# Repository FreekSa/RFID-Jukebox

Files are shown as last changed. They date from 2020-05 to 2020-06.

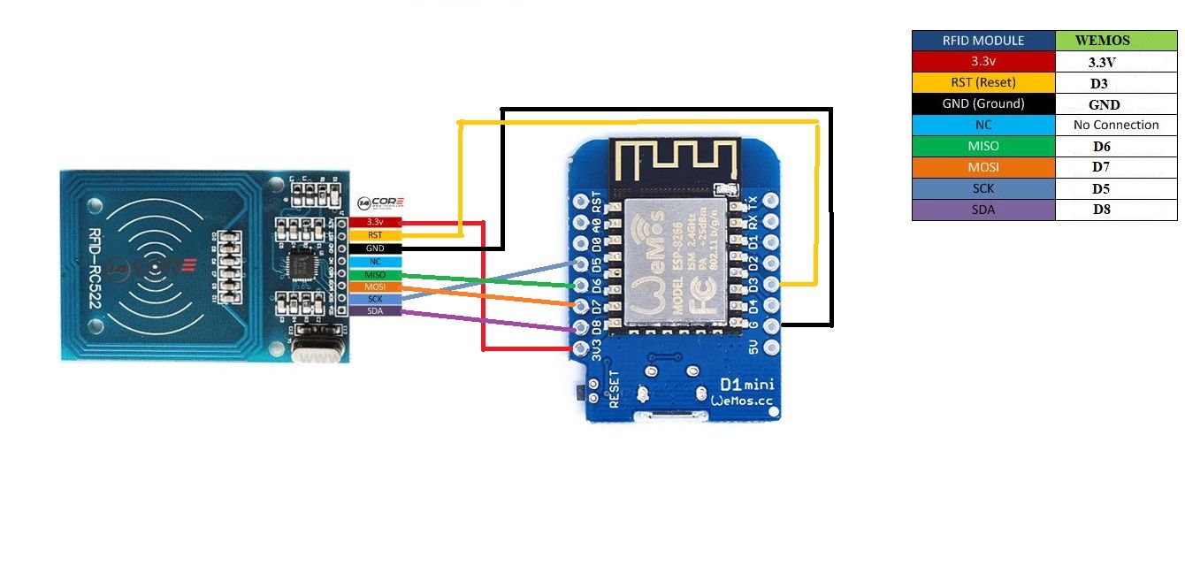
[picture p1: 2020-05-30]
rfid pinout.jpg

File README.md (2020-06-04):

# RFID-Jukebox

Ik zag een artikel passeren over iemand die een kickstarter project had nagebouwd.
Link: https://imgur.com/a/aiS5xp7
Ik had nog een Wemos D1 mini v3 liggen die nog geen bestemming had gekregen en een raspberry pi 3. Daarnaast had ik reeds een RFID module (MFRC522) met enkele NFC tags.

Na wat zoeken vond ik zijn code op github: https://github.com/paulmassen/volumio-rfid-esp8266
Zijn code was onvolledig; na een test bleek al snel dat hij een kaart scant en een link stuurt naar Volumio, maar als een tag bleef liggen speelde hij na 3 seconden het nummer opnieuw af. Met een "if" structuur is deze aangepast. Functie: Nu leest hij de tag en als deze tag voordien al gescand is dan moet hij niks doen.

Wat heb je nodig voor dit project (bijhorende links waar ik mijn materiaal kocht):

Wemos D1 mini v3: https://opencircuit.be/Product/WeMos-D1-mini-V3.1-Wifi-Module</br>
NFC reader (headers moeten zelf gesoldeerd worden): https://opencircuit.be/Product/RC522-RFID-Reader-writer-module-kit-13.56MHz</br>
Raspberry pi 3 (elke pi met ingebouwde wifi zou moeten werken): https://www.kiwi-electronics.nl/raspberry-pi-3-model-b-plus</br>
HDMI naar VGA adapter: kost 5€ in de action. We gebruiken deze om de audio jack die achteraan de vga poort zit te gebruiken en zo mooie kwaliteit als output te krijgen.</br>
NFC tags/stickers: kocht op alliexpress voor 1€ 10 NFC stickers (In België betaal je snel 15€ voor 10 stickers) Ik kocht er 50 in een keer en betaalde 5€ excl verzendkosten. (moet je wel een maand wachten).

Daarnaast heb ik zelf een 3D printer en designde dus de case, deksel met holte voor de schijfjes en aparte schijfjes in fusion360 (gratis software voor hobbyisten ;-) . (stl's zijn toegevoegd, alsook fusion files)

Aan jou om alles te printen. Kan bvb met online service 3DHubs of in een fablab/makerspace in je buurt.
Nu we alles hebben kunnen we alles in elkaar prutsen. In bijgevoegde foto zie je hoe je de nfc reader verbind met je wemos D1. (pinnen heb ik niet aan de RFID gesoldeerd, wel aan de wemos D1. (eigen keuze :) ).

Nu alles verbonden is, volgt het programmeren van de wemos D1.
Open het "DumpInfo.ino" bestand in de ARDUINO IDE.
Arduino kent ons boardje niet. Dus moeten we een link toevoegen zodat hij deze kent. Dit doe je als volgt:
Klik op Bestand, Voorkeuren en plak de link: Additionele boards beheer URL: http://arduino.esp8266.com/stable/package_esp8266com_index.json

Nu kent hij ons borde, maar om de NFC lezer te gebruiken moeten we een bibliotheek installeren. Klik daarvoor op: Hulpmiddelen, Bibliotheken beheren. Zoek naar: MFRC522 en klik op Installeer.

Daarna selecteer je bij Boards: Wemos D1 mini pro V3. en bij poorten de juist COM.

Als alles is aangesloten open je het bestand: "DumpInfo.ino", dit vind je in de github of onder: Voorbeelden, MFRC522, Dumpinfo.
Verander SSPin naar D8 ipv 10 en upload naar je bord. Ga naar Hulpmiddelen en open de seriele poort. Controleer dat hij zeker op 9600 Baud staat. Scan je tag en kopieer ergens de Tag UID (vb Kladblok). Scan al je tags die je wil gebruiken en maak een overzichtje naar welke afspeellijst je deze wil koppelen.

Nu open je de "RFID_met_volumio.ino". Je plakt je tag onder clients tag. (verander deze met jou gescande UID per tag).
Daaronder verander je de url naar jou afspeellijst (leg ik uit onder het onderdeel Volumio)
Daarna uploaden naar je board (vergeet je poort niet te selecteren!)

Volumio

Extra info: Als Volumio met geen wifi-netwerk verbonden is dan maakt hij een eigen hotspot aan. Deze heet Volumio en gebruiken we.
Wachtwoord verander je in de volumio settings. Deze vind je door met de hotspot te verbinden en in je browser naar: volumio.local te surfen.

Volumio flashen op je sd kaart doe je bvb via win32DiskImager. Dit leg ik niet verder uit. Hiervan vind je veel tutorials op internet. zoek onder: img naar sd kaart flashen.

Verbindt via wifi op je pc met Volumio. Wachtwoord: Volumio. Surf naar http://volumio.local

Als je volumio voor de eerste keer start stelt hij wat vragen. Belangrijk is dat je HDMI als default selecteert en niet de audio jack. De raspberry pi's audio jack heeft geen versterker dus produceert ruis. Via HDMI kan je dan achteraan de adapter je jack insteken.

Nu alles van geluid in orde is moeten we afspeellijsten maken. Kort uitgelegd: De wemos stuurt een link naar een afspeellijst die in volumio staat. Je gaat dus naar muziekbibliotheek en steekt een usb stick in met muziek of muziek die op de sd kaart staat (leg ik zo meteen uit hoe je er op zet). Klik op de 3 puntjes naast een mapje en klik op toevoegen aan afspeellijst. Geef een naam en klik op Nieuw.

Muziek overzetten vanop je pc:
Open een verkenner en typ in de url: \\volumio.local
Nu kan je muziek in de Internal storage slepen en vind je terug in volumio in Muziekbibliotheek.

ARDUINO:
Vul de naam van je afspeellijst in de plaats van mijn afspeellijstnamen in arduino met enkele regels daarboven je gescande tagnummer per afspeellijst. Vergeet niet: een spatie tussen je afspeellijst doe je weg en vul je %20 in. (zie in mijn namen van afspeellijsten in het bestand).

Nu hoef je zelf nog je foto's te maken. (mijn breedte van fotos was 2.7cm om zo te passen. Veel prutswerk om deze mooi op het schijfje te krijgen. Op de achterkant plak je dan je nfc sticker. Mooiste kwaliteit is printen op fotopapier (mat zodat de vingerafdrukken er niet aanplakken).

Vergeet geen play en pauze schijfje! :-)

Succes en veel plezier!

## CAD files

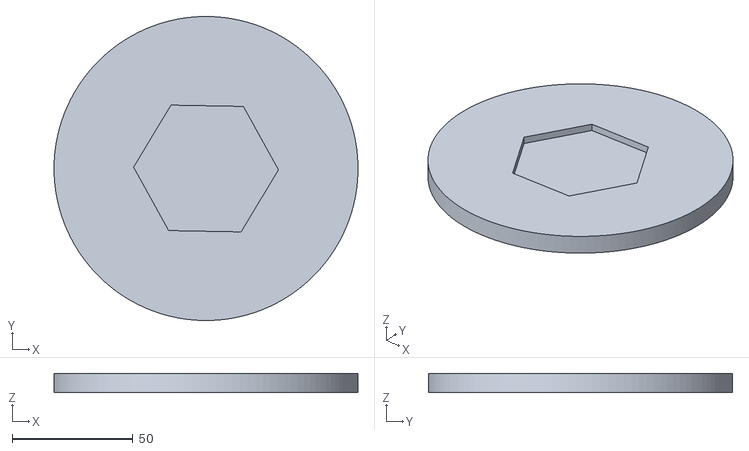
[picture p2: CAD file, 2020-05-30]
rfid bovenkant v1.stl
126.0 x 126.0 x 8.00

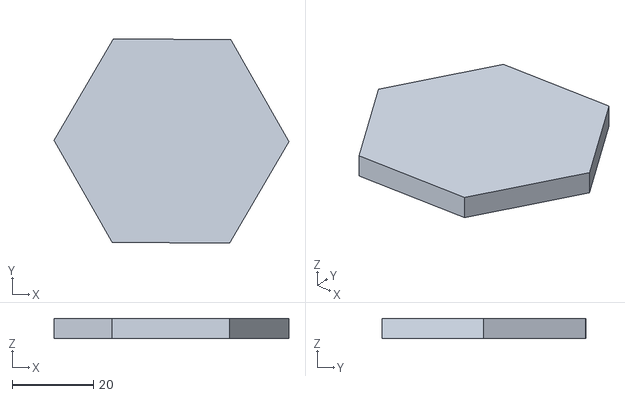
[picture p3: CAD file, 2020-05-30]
schijfje v1.stl
57.7 x 50.2 x 5.00

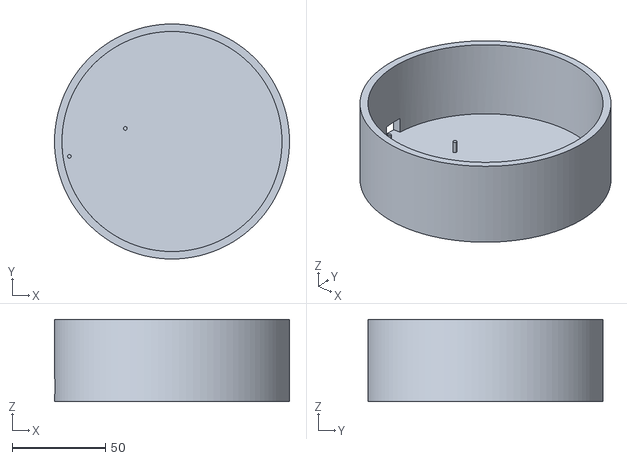
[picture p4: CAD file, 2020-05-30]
rfid volumio v1.stl
126.0 x 126.0 x 44.0

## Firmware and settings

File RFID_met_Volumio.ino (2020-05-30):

/*

   --------------------------------------------------------------------------------------------------------------------
   Example sketch/program showing how to read data from a PICC to serial.
   --------------------------------------------------------------------------------------------------------------------
   This is a MFRC522 library example; for further details and other examples see: https://github.com/miguelbalboa/rfid

   Example sketch/program showing how to read data from a PICC (that is: a RFID Tag or Card) using a MFRC522 based RFID
   Reader on the Arduino SPI interface.

   When the Arduino and the MFRC522 module are connected (see the pin layout below), load this sketch into Arduino IDE
   then verify/compile and upload it. To see the output: use Tools, Serial Monitor of the IDE (hit Ctrl+Shft+M). When
   you present a PICC (that is: a RFID Tag or Card) at reading distance of the MFRC522 Reader/PCD, the serial output
   will show the ID/UID, type and any data blocks it can read. Note: you may see "Timeout in communication" messages
   when removing the PICC from reading distance too early.

   If your reader supports it, this sketch/program will read all the PICCs presented (that is: multiple tag reading).
   So if you stack two or more PICCs on top of each other and present them to the reader, it will first output all
   details of the first and then the next PICC. Note that this may take some time as all data blocks are dumped, so
   keep the PICCs at reading distance until complete.

   @license Released into the public domain.

   Typical pin layout used:
   -----------------------------------------------------------------------------------------
               MFRC522      Arduino       Arduino   Arduino    Arduino          Arduino
               Reader/PCD   Uno/101       Mega      Nano v3    Leonardo/Micro   Pro Micro
   Signal      Pin          Pin           Pin       Pin        Pin              Pin
   -----------------------------------------------------------------------------------------
   RST/Reset   RST          9             5         D9         RESET/ICSP-5     RST
   SPI SS      SDA(SS)      10            53        D10        10               10
   SPI MOSI    MOSI         11 / ICSP-4   51        D11        ICSP-4           16
   SPI MISO    MISO         12 / ICSP-1   50        D12        ICSP-1           14
   SPI SCK     SCK          13 / ICSP-3   52        D13        ICSP-3           15
*/

#include <SPI.h>
#include <MFRC522.h>
#include <ESP8266WiFi.h>
#include <ESP8266HTTPClient.h>
#define RST_PIN         9          // Configurable, see typical pin layout above
#define SS_PIN          D8         // Configurable, see typical pin layout above
const char *ssid =  "Volumio"; // change according to your Network - cannot be longer than 32 characters!
const char *pass =  "Volumio"; // change according to your Network
MFRC522 mfrc522(SS_PIN, RST_PIN);  // Create MFRC522 instance
const char* host = "192.168.0.1";
const int httpPort = 80;
String GescandekaartCache = "";
void setup() {
  Serial.begin(9600);
  Serial.print("Connecting to ");
  Serial.println(ssid);
  WiFi.begin(ssid, pass);

  int retries = 0;
  while ((WiFi.status() != WL_CONNECTED) && (retries < 10)) {
    retries++;
    delay(500);
    Serial.print(".");
  }
  if (WiFi.status() == WL_CONNECTED) {
    Serial.println(F("WiFi connected"));
  }
  Serial.println(F("Ready!"));
  Serial.println(F("======================================================"));
  Serial.println(F("Scan for Card and print UID:"));
  WiFiClient client;
  // Initialize serial communications with the PC
  while (!Serial);    // Do nothing if no serial port is opened (added for Arduinos based on ATMEGA32U4)
  SPI.begin();      // Init SPI bus
  mfrc522.PCD_Init();   // Init MFRC522
  mfrc522.PCD_DumpVersionToSerial();  // Show details of PCD - MFRC522 Card Reader details
  Serial.println(F("Scan PICC to see UID, SAK, type, and data blocks..."));
  //   if (!client.connect(host, httpPort)) {
  //    Serial.println("connection failed");
  //    return;
  //  }
}

void loop()
{
  // Look for new cards
  if ( ! mfrc522.PICC_IsNewCardPresent())
  {
    return;
  }
  // Select one of the cards
  if ( ! mfrc522.PICC_ReadCardSerial())
  {
    return;
  }
  //Show UID on serial monitor
  Serial.print("UID tag :");
  String content = "";
  byte letter;
  for (byte i = 0; i < mfrc522.uid.size; i++)
  {
    Serial.print(mfrc522.uid.uidByte[i] < 0x10 ? " 0" : " ");
    Serial.print(mfrc522.uid.uidByte[i], HEX);
    content.concat(String(mfrc522.uid.uidByte[i] < 0x10 ? " 0" : " "));
    content.concat(String(mfrc522.uid.uidByte[i], HEX));
  }
  Serial.println();
  Serial.print("Message : ");
  content.toUpperCase();
  // WiFiClient client;
  if(GescandekaartCache!=content.substring(1)){
     GescandekaartCache=content.substring(1);
   if (content.substring(1) == "04 86 BA BA CD 66 80") //change here the UID of the card/cards that you want to give access 
    {
    Serial.println("Authorized access");      //kaart 1
    Serial.println();
    if (WiFi.status() == WL_CONNECTED) { //Check WiFi connection status
      Serial.println("Wifi is connected, proceed request");
      HTTPClient http;  //Declare an object of class HTTPClient

      http.begin("http://volumio.local/api/v1/commands/?cmd=pause");  //Specify request destination
      int httpCode = http.GET();                                                                  //Send the request

      if (httpCode > 0) { //Check the returning code

        String payload = http.getString();   //Get the request response payload
        Serial.println(payload);                     //Print the response payload
      }

      http.end();   //Close connection

    }
    else {
      // if you couldn't make a connection:
      Serial.println("connection failed");
    }
    delay(500);
  }

  else if (content.substring(1) == "04 82 BA BA CD 66 80") //change here the UID of the card/cards that you want to give access
    {
    Serial.println("Authorized access");     //kaart 2
    Serial.println();
    if (WiFi.status() == WL_CONNECTED) { //Check WiFi connection status
      Serial.println("Wifi is connected, proceed request");
      HTTPClient http;  //Declare an object of class HTTPClient

      http.begin("http://volumio.local/api/v1/commands/?cmd=play");  //Specify request destination
      int httpCode = http.GET();                                                                  //Send the request

      if (httpCode > 0) { //Check the returning code

        String payload = http.getString();   //Get the request response payload
        Serial.println(payload);                     //Print the response payload
      }

      http.end();   //Close connection

    }
    else {
      // if you couldn't make a connection:
      Serial.println("connection failed");
    }
    delay(500);
  }
  else if (content.substring(1) == "04 99 BB BA CD 66 80") //change here the UID of the card/cards that you want to give access
    {
    Serial.println("Authorized access");    //kaart 3
    Serial.println();
    if (WiFi.status() == WL_CONNECTED) { //Check WiFi connection status
      Serial.println("Wifi is connected, proceed request");
      HTTPClient http;  //Declare an object of class HTTPClient

      http.begin("http://volumio.local/api/v1/commands/?cmd=playplaylist&name=Angèle");  //Specify request destination
      int httpCode = http.GET();                                                                  //Send the request

      if (httpCode > 0) { //Check the returning code

        String payload = http.getString();   //Get the request response payload
        Serial.println(payload);                     //Print the response payload
      }

      http.end();   //Close connection

    }
    else {
      // if you couldn't make a connection:
      Serial.println("connection failed");
    }
    delay(500);
  }
  else if (content.substring(1) == "04 B0 C2 BA CD 66 80") //change here the UID of the card/cards that you want to give access 
    {
    Serial.println("Authorized access");      //kaart 4
    Serial.println();
    if (WiFi.status() == WL_CONNECTED) { //Check WiFi connection status
      Serial.println("Wifi is connected, proceed request");
      HTTPClient http;  //Declare an object of class HTTPClient

      http.begin("http://volumio.local/api/v1/commands/?cmd=playplaylist&name=Art%20Sullivan");  //Specify request destination
      int httpCode = http.GET();                                                                  //Send the request

      if (httpCode > 0) { //Check the returning code

        String payload = http.getString();   //Get the request response payload
        Serial.println(payload);                     //Print the response payload
      }

      http.end();   //Close connection

    }
    else {
      // if you couldn't make a connection:
      Serial.println("connection failed");
    }
    delay(500);
  }
  else if (content.substring(1) == "04 B4 C2 BA CD 66 80") //change here the UID of the card/cards that you want to give access
    {
    Serial.println("Authorized access");      //kaart 5
    Serial.println();
    if (WiFi.status() == WL_CONNECTED) { //Check WiFi connection status
      Serial.println("Wifi is connected, proceed request");
      HTTPClient http;  //Declare an object of class HTTPClient

      http.begin("http://volumio.local/api/v1/commands/?cmd=playplaylist&name=Billie%20Eilish");  //Specify request destination
      int httpCode = http.GET();                                                                  //Send the request

      if (httpCode > 0) { //Check the returning code

        String payload = http.getString();   //Get the request response payload
        Serial.println(payload);                     //Print the response payload
      }

      http.end();   //Close connection

    }
    else {
      // if you couldn't make a connection:
      Serial.println("connection failed");
    }
    delay(500);
  }
  else if (content.substring(1) == "04 AC C2 BA CD 66 80") //change here the UID of the card/cards that you want to give access
    {
    Serial.println("Authorized access");      //kaart 6
    Serial.println();
    if (WiFi.status() == WL_CONNECTED) { //Check WiFi connection status
      Serial.println("Wifi is connected, proceed request");
      HTTPClient http;  //Declare an object of class HTTPClient

      http.begin("http://volumio.local/api/v1/commands/?cmd=playplaylist&name=Claude%20Francois");  //Specify request destination
      int httpCode = http.GET();                                                                  //Send the request

      if (httpCode > 0) { //Check the returning code

        String payload = http.getString();   //Get the request response payload
        Serial.println(payload);                     //Print the response payload
      }

      http.end();   //Close connection

    }
    else {
      // if you couldn't make a connection:
      Serial.println("connection failed");
    }
    delay(500);
  }
  else if (content.substring(1) == "04 A8 C2 BA CD 66 80") //change here the UID of the card/cards that you want to give access 
    {
    Serial.println("Authorized access");      //kaart 7
    Serial.println();
    if (WiFi.status() == WL_CONNECTED) { //Check WiFi connection status
      Serial.println("Wifi is connected, proceed request");
      HTTPClient http;  //Declare an object of class HTTPClient

      http.begin("http://volumio.local/api/v1/commands/?cmd=playplaylist&name=Compact%20Disk%20Dummies");  //Specify request destination
      int httpCode = http.GET();                                                                  //Send the request

      if (httpCode > 0) { //Check the returning code

        String payload = http.getString();   //Get the request response payload
        Serial.println(payload);                     //Print the response payload
      }

      http.end();   //Close connection

    }
    else {
      // if you couldn't make a connection:
      Serial.println("connection failed");
    }
    delay(500);
  }
  else if (content.substring(1) == "04 C0 C2 BA CD 66 80") //change here the UID of the card/cards that you want to give access
    {
    Serial.println("Authorized access");      //kaart 8
    Serial.println();
    if (WiFi.status() == WL_CONNECTED) { //Check WiFi connection status
      Serial.println("Wifi is connected, proceed request");
      HTTPClient http;  //Declare an object of class HTTPClient

      http.begin("http://volumio.local/api/v1/commands/?cmd=playplaylist&name=Dua%20Lipa");  //Specify request destination
      int httpCode = http.GET();                                                                  //Send the request

      if (httpCode > 0) { //Check the returning code

        String payload = http.getString();   //Get the request response payload
        Serial.println(payload);                     //Print the response payload
      }

      http.end();   //Close connection

    }
    else {
      // if you couldn't make a connection:
      Serial.println("connection failed");
    }
    delay(500);
  }
  else if (content.substring(1) == "04 96 BA BA CD 66 80") //change here the UID of the card/cards that you want to give access
    {
    Serial.println("Authorized access");      //kaart 9
    Serial.println();
    if (WiFi.status() == WL_CONNECTED) { //Check WiFi connection status
      Serial.println("Wifi is connected, proceed request");
      HTTPClient http;  //Declare an object of class HTTPClient

      http.begin("http://volumio.local/api/v1/commands/?cmd=playplaylist&name=Ertebrekers");  //Specify request destination
      int httpCode = http.GET();                                                                  //Send the request

      if (httpCode > 0) { //Check the returning code

        String payload = http.getString();   //Get the request response payload
        Serial.println(payload);                     //Print the response payload
      }

      http.end();   //Close connection

    }
    else {
      // if you couldn't make a connection:
      Serial.println("connection failed");
    }
    delay(500);
  }
  else if (content.substring(1) == "04 8A BA BA CD 66 80") //change here the UID of the card/cards that you want to give access        
    {
    Serial.println("Authorized access");      //Kaart 10
    Serial.println();
    if (WiFi.status() == WL_CONNECTED) { //Check WiFi connection status
      Serial.println("Wifi is connected, proceed request");
      HTTPClient http;  //Declare an object of class HTTPClient

      http.begin("http://volumio.local/api/v1/commands/?cmd=playplaylist&name=Flume");  //Specify request destination
      int httpCode = http.GET();                                                                  //Send the request

      if (httpCode > 0) { //Check the returning code

        String payload = http.getString();   //Get the request response payload
        Serial.println(payload);                     //Print the response payload
      }

      http.end();   //Close connection

    }
    else {
      // if you couldn't make a connection:
      Serial.println("connection failed");
    }
    delay(500);
  }
  else if (content.substring(1) == "04 C3 C3 BA CD 66 80") //change here the UID of the card/cards that you want to give access        /
    {
    Serial.println("Authorized access");      //Kaart 11
    Serial.println();
    if (WiFi.status() == WL_CONNECTED) { //Check WiFi connection status
      Serial.println("Wifi is connected, proceed request");
      HTTPClient http;  //Declare an object of class HTTPClient

      http.begin("http://volumio.local/api/v1/commands/?cmd=playplaylist&name=Gestapo%20Knallmuzik");  //Specify request destination
      int httpCode = http.GET();                                                                  //Send the request

      if (httpCode > 0) { //Check the returning code

        String payload = http.getString();   //Get the request response payload
        Serial.println(payload);                     //Print the response payload
      }

      http.end();   //Close connection

    }
    else {
      // if you couldn't make a connection:
      Serial.println("connection failed");
    }
    delay(500);
  }
  else if (content.substring(1) == "0000") //change here the UID of the card/cards that you want to give access        
    {
    Serial.println("Authorized access");      //Kaart 12
    Serial.println();
    if (WiFi.status() == WL_CONNECTED) { //Check WiFi connection status
      Serial.println("Wifi is connected, proceed request");
      HTTPClient http;  //Declare an object of class HTTPClient

      http.begin("http://volumio.local/api/v1/commands/?cmd=playplaylist&name=Goose");  //Specify request destination
      int httpCode = http.GET();                                                                  //Send the request

      if (httpCode > 0) { //Check the returning code

        String payload = http.getString();   //Get the request response payload
        Serial.println(payload);                     //Print the response payload
      }

      http.end();   //Close connection

    }
    else {
      // if you couldn't make a connection:
      Serial.println("connection failed");
    }
    delay(500);
  }
  else if (content.substring(1) == "0000") //change here the UID of the card/cards that you want to give access        
    {
    Serial.println("Authorized access");      //Kaart 13
    Serial.println();
    if (WiFi.status() == WL_CONNECTED) { //Check WiFi connection status
      Serial.println("Wifi is connected, proceed request");
      HTTPClient http;  //Declare an object of class HTTPClient

      http.begin("http://volumio.local/api/v1/commands/?cmd=playplaylist&name=Gorillaz");  //Specify request destination
      int httpCode = http.GET();                                                                  //Send the request

      if (httpCode > 0) { //Check the returning code

        String payload = http.getString();   //Get the request response payload
        Serial.println(payload);                     //Print the response payload
      }

      http.end();   //Close connection

    }
    else {
      // if you couldn't make a connection:
      Serial.println("connection failed");
    }
    delay(500);
  }
  else if (content.substring(1) == "04 8E BA BA CD 66 80") //change here the UID of the card/cards that you want to give access        
    {
    Serial.println("Authorized access");      //Kaart 14
    Serial.println();
    if (WiFi.status() == WL_CONNECTED) { //Check WiFi connection status
      Serial.println("Wifi is connected, proceed request");
      HTTPClient http;  //Declare an object of class HTTPClient

      http.begin("http://volumio.local/api/v1/commands/?cmd=playplaylist&name=Het%20zesde%20metaal");  //Specify request destination
      int httpCode = http.GET();                                                                  //Send the request

      if (httpCode > 0) { //Check the returning code

        String payload = http.getString();   //Get the request response payload
        Serial.println(payload);                     //Print the response payload
      }

      http.end();   //Close connection

    }
    else {
      // if you couldn't make a connection:
      Serial.println("connection failed");
    }
    delay(500);
  }
  else if (content.substring(1) == "04 9D C3 BA CD 66 80") //change here the UID of the card/cards that you want to give access        
    {
    Serial.println("Authorized access");      //Kaart 15
    Serial.println();
    if (WiFi.status() == WL_CONNECTED) { //Check WiFi connection status
      Serial.println("Wifi is connected, proceed request");
      HTTPClient http;  //Declare an object of class HTTPClient

      http.begin("http://volumio.local/api/v1/commands/?cmd=playplaylist&name=De%20jeugd%20van%20tegenwoordig");  //Specify request destination
      int httpCode = http.GET();                                                                  //Send the request

      if (httpCode > 0) { //Check the returning code

        String payload = http.getString();   //Get the request response payload
        Serial.println(payload);                     //Print the response payload
      }

      http.end();   //Close connection

    }
    else {
      // if you couldn't make a connection:
      Serial.println("connection failed");
    }
    delay(500);
  }
  else if (content.substring(1) == "0000") //change here the UID of the card/cards that you want to give access        
    {
    Serial.println("Authorized access");      //Kaart 16
    Serial.println();
    if (WiFi.status() == WL_CONNECTED) { //Check WiFi connection status
      Serial.println("Wifi is connected, proceed request");
      HTTPClient http;  //Declare an object of class HTTPClient

      http.begin("http://volumio.local/api/v1/commands/?cmd=playplaylist&name=Major%20Lazer");  //Specify request destination
      int httpCode = http.GET();                                                                  //Send the request

      if (httpCode > 0) { //Check the returning code

        String payload = http.getString();   //Get the request response payload
        Serial.println(payload);                     //Print the response payload
      }

      http.end();   //Close connection
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
